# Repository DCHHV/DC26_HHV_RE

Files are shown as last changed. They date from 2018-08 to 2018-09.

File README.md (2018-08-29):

# DC26 HHV RE Challenge
DEF CON 26 Hardware Hacking Village Reverse Engineering Challenge

## Overview

This year's board features two challenge. The first part requires entering in the correct passcode using the four onboard buttons (labeled A, B, C, and D). Once the correct passcode has been entered, the middle, green LED will come on and the flag will be printed out via the serial interface. The second part of the challenge requires understanding how the second IC (the first being the ATtiny microcontroller) is used and manipulating that. The bottom, green LED will come on once that part is solved.

There are multiple ways to solve these challenges, and they are meant to be fun. If you're having trouble, or if you find a bug, reach out to [mediumrehr](https://www.twitter.com/mediumrehr)

Good luck!

## Instuctions

### Assembly
If your challenge isn't assembled, please see the hardware section for details on assembly. Most parts are explanitory as to where they go. For the surface mount parts, the 3-pack of resistors are for the LEDs, the 2-pack of resistors is for the RX line (only one of the resistors are necessary), and the single capacitor is used to reduce noise on the VCC input.

### Programming
There are two methods of loading the firmware onto the challenge board. Both require the same steps to start.

1. Connect the test points on the bottom of the challenge board to an arduino and add a capacitor between reset and GND on the Arduino UNO.

```
GND --> GND
SCK --> pin 13
MISO -> pin 12
MOSI -> pin 11
CS ---> pin 10
VCC --> 5V
```
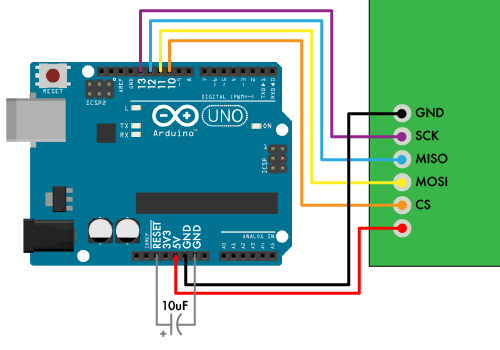
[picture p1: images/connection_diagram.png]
Connection diagram from programming


Note 1: If using an Uno (or another arduino board with 5V IO pins), make sure VCC is connected to 5V when programming. If IO pins are 3.3V, connect VCC to 3.3V when programming.

2. Bridge the two pads to the bottom right of the buttons.

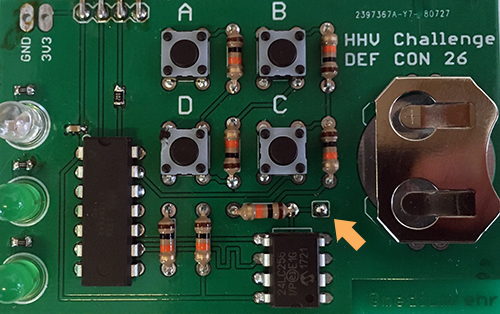
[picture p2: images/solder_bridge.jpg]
Programming solder bridge


3. Install the [Arduino IDE](https://www.arduino.cc/en/Main/Software "Arduino IDE Download").

4. Configure the Arduino as an ISP and add support to the Arduino IDE for the Attiny84 by [following this guide](http://highlowtech.org/?p=1695 "Guide for adding ATtiny84 support in Arduino IDE").

Now, here's where things split. You can either use the Arduino IDE to compile and upload the firmware onto the board, or you can use avrdude to program the already compiled code onto the board. The former requires installing a couple Arduino IDE libraries.

**Using the Arduino IDE**

1. Install the [TinyWireM](https://github.com/adafruit/TinyWireM) library by cloning/downloading and unzipping the project into `Arduino/libraries`, likely in your Documents folder.

2. Connect the Arduino to the computer and under the `Tools` menu, set `Board` to `ATtiny24/44/84`, `Processor` to `ATtiny84`, `Clock` to `Internal 1 MHz`, `Port` should be whatever port the Arduino UNO is plugged into, and `Programmer` to `Arduino as ISP`.

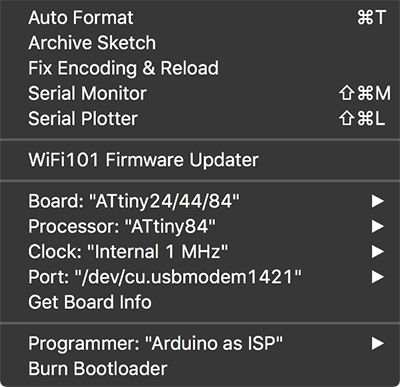
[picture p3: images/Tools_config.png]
Arduino Tools configuration


3. Burn the bootloader (and set the clock speed) by going back to `Tools` and clicking `Burn Bootloader`

4. Once the bootloader is burned onto the Attiny84, open `DC26_HHV_RE_setup.ino` and click the right-pointing arrow in the top left corner to upload the sketch. This will configure the challenges board before loading the challenge. The red LED should come on once this step is finished (if the LED hasn't come on after a couple seconds, it's likely something went wrong).

5. Open and upload `DC26_HHV_RE_obfuscated.ino` (DC26_HHV_RE.ino does the same thing, it's just easier to read and might give away some of the fun of the game if you read the wrong line or two) to finish loading the challenge.

Ensure that the red LED appears briefly upon pressing one of the buttons. If it does, you're good to go! Disconnect the programming wires and Arduino power before putting a battery into the battery holder.

6. Remove the solder bridge on the two pads to the bottom right of the buttons.

**Using avrdude**

avrdude has the benefit of allowing you to flash the hex file, and therefor not needing to install another library, or possibly spoil the surprises of the challenge.

1. Make sure you you know the location of avrdude and its config file, your programmer id, and the path to the mounted usb device. The config file will come after `-C`, the programmer id after `-c`, and the programmer mount location after `-P`.

In Mac OS, the avrdude will likely be under `/Applications/Arduino.app/Contents/Java/hardware/tools/avr/bin/avrdude` and its config will likely be under `/Applications/Arduino.app/Contents/Java/hardware/tools/avr/etc/avrdude.conf`. If you're using Windows, avrdude will likely be under `C:\Program Files (x86)\Arduino\hardware\tools\avr\bin\avrdude` and its config will likely be under `C:\Program Files (x86)\Arduino\hardware\tools\avr\etc\avrdude.conf`.

If you're using an Arduino as ISP, the programmer id is likely `stk500v1`, if you're using a bus pirate, the id is likely `buspirate`. For more examples of programmer ids, see [Ladyada's Avrdude Tutorial](http://www.ladyada.net/learn/avr/avrdude.html).

To find the programmer's port, follow [this guide](https://www.mathworks.com/help/supportpkg/arduinoio/ug/find-arduino-port-on-windows-mac-and-linux.html), or something similar.

2. Burn the bootloader. This script will setup the attiny84 bootloader and configure it to use the 1MHz internal clock:
```
/path/to/avrdude -C /path/to/avrdude.conf -v -p attiny84 -c stk500v1 -P /path/to/usbport -b 19200 -e -U efuse:w:0xff:m -U hfuse:w:0xdf:m -U lfuse:w:0x62:m
```

3. Load and run the setup sketch:
```
/path/to/avrdude -C /path/to/avrdude.conf -v -V -p attiny84 -c stk500v1 -P /path/to/usbport -b 19200 -U flash:w:/path/to/DC26_HHV_RE_setup.1MHz.hex:i
```

This will configure the challenges board before loading the challenge. The red LED should come on once this step is finished (if the LED hasn't come on after a couple seconds, it's likely something went wrong).

4. Load and run the challenge sketch:
```
/path/to/avrdude -C /path/to/avrdude.conf -v -V -p attiny84 -c stk500v1 -P /path/to/usbport -b 19200 -U flash:w:/path/to/DC26_HHV_RE.1MHz.hex:i
```

Ensure that the red LED appears briefly upon pressing one of the buttons. If it does, you're good to go! Disconnect the programming wires and Arduino power before putting a battery into the battery holder.

6. Remove the solder bridge on the two pads to the bottom right of the buttons.

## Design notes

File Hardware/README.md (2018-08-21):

# DC26 HHV RE Challenge
DEF CON 26 Hardware Hacking Village Reverse Engineering Challenge

## Assembly

The schematic, layout, and BOM are all included in this folder. Before assembling, make sure you have correct parts, and the correct amount of each.

```
SMD parts:
3 75 Ohm 0603 resistors
1* 1k Ohm 0805 resistor
1 0.1uF 0603 capacitor

TH parts:
1 ATtiny84 IC
1 24LC256 IC
4 Tactile switches 6mm
7 10k Ohm resistors
2 Green LEDs 5mm
1 Red LED 5mm
1 CR2032 battery holder
1 CR2032 battery

Not included, but likely necessary:
a handful of male headers
a serial reader
some connection wire

* if you received parts at DEF CON, you likely received this as a pack of 2, but you'll only need one
```

Below is what the assembled challenge board should look like:

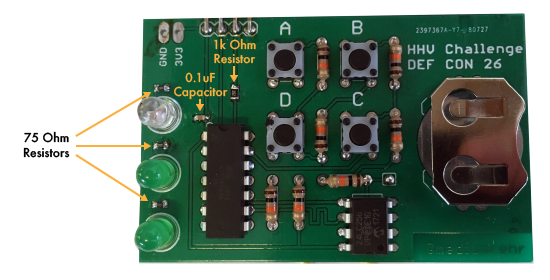
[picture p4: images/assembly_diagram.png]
Assembly diagram


Most of the through hole components can only go once place. The ATtiny and 24LC256 are directional, so make sure they oriented correctly (notches should line up with silkscreened indicators). The LEDs should be in the order of red (or clear), green, green from the top down. Surface mount componets are noted in the image above. The three 75 Ohm resistors should be placed directly above each LED, capacitor should be placed to the top left of the ATtiny84, and the 1k Ohm resistor should be placed on the RX serial line (above the ATtiny84).

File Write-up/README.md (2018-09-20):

## Write up

#### Pre challenge

Before starting the challenges, it's important to identify the 4-pin header at the top left of the board. This is the UART interface that is used to transmit the flags once they are unlocked. It also plays a role in solving part 1.

#### Part 1: Cracking the Passcode
There are a few ways to approach this problem. The intended way of solving the challeng is to perform a [side-channel attack](https://en.wikipedia.org/wiki/Side-channel_attack), but it is also possible to brute-force the passcode (there wasn't anything preventing this) since there are only 65536 possible combinations.

Using a logic analyzer and calculating the time delay between when a button is reported via UART and when the LED illuminates as feedback from a press, it's possible to deduce whether or not a passcode entry was correct (as long as the prior entries were correct). The image below shows three button presses; the first is correct and there is a 20ms delay between the UART (channel 2 in the image) report and the LED flashing (channel 3 in the image). The second button press is incorrect, resulting in a much shorter delay between report and flash. The third press will result in a short delay regardless or correctness since the system is designed to ignore following inputs once an incorrect passcode button press is entered.

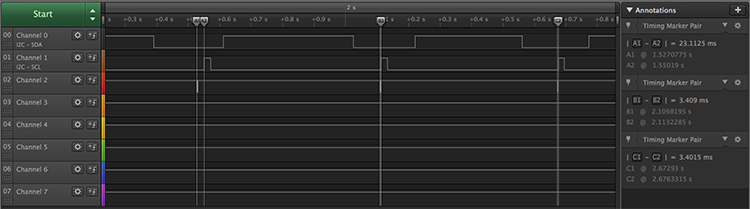
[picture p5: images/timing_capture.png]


The correct passcode is 14431212, and once it is entered, the middle LED will turn on and the flag "h3y_wh4ts_t3h_p4ssw0rd?" will be transmitted via the UART interface.

#### Part 2: Memory Manipulation

The second challenge utilizes the [24LC256 EEPROM](https://www.digikey.com/product-detail/en/microchip-technology/24LC256-I-P/24LC256-I-P-ND/273431). The microcontoller checks a specific address of the EEPROM on start-up, and if that address is set to a specific value, it will pass the challenge 2 check, turn on the bottom green LED, and output the flag via UART. There are two ways to start this challenge, either sniff the i2c lines running to the EEPROM to notice that the attiny is checking address 0x5A for a value on startup, or skip that step and dump the EEPROM. Dumping the EEPROM and entering the values into a hex to ascii converter will reveal the string "set address 0x5A to 0x26" starting at address 0x3.

There are two ways to go from here, you can either rewrite the EEPROM so that address 0x5A is set to 0x26, or you can disconnect the i2c lines from the EEPROM and create a device that spoofs the EEPROM interaction. The former route requires bridging the jumper (to the bottom right of the passcode buttons), disconnecting the write protect pin of the EEPROM. It's pulled high by default, but bridging that jumper pulls the pin low, disabling write protection and allowing the EEPROM to be changed.

Disconnecting the i2c lines from the EEPROM and connecting them to a new device that spoofs the interaction is also a way to pass this challenge. Using a microcontroller, you can set it up as an i2c slave that listens for requests on address 0x5A. Once an address comes through, respond with the value 0x26. Once the check is passed, the flag "0h_1_r3m3mb3r_n0w!" will be transmitted via the UART interface.

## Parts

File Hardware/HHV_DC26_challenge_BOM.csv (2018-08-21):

DC26 HHV RE Challenge BOM
Part | Value | Device | Package | Description | MF | MPN | Digikey PN | Digikey link
BT1 |  | Batter Holder |  | RETAINER BATT CR2025/2032 PC PIN | Linx Technologies Inc | BAT-HLD-001-THM | BAT-HLD-001-THM-ND | https://www.digikey.com/product-detail/en/linx-technologies-inc/BAT-HLD-001-THM/BAT-HLD-001-THM-ND/3044009
C1 | 0.1uF | Capacitor | 603 | CAP CER 0.1UF 25V X5R 0603 | Samsung Electro-Mechanics | CL10A104KA8NNNC | 1276-1857-1-ND | https://www.digikey.com/product-detail/en/samsung-electro-mechanics/CL10A104KA8NNNC/1276-1857-1-ND/3889943
D1 | Green | LED5MM | LED_5MM | LED GREEN DIFFUSED 5MM ROUND T/H | Marktech Optoelectronics | MT2118-G-A | 1125-1184-ND | https://www.digikey.com/product-detail/en/marktech-optoelectronics/MT2118-G-A/1125-1184-ND/4214619
D2 | Green | LED5MM | LED_5MM | LED GREEN DIFFUSED 5MM ROUND T/H
D3 | Red | LED5MM | LED_5MM | LED RED CLEAR 5MM ROUND T/H | Cree Inc. | C503B-RAN-CZ0C0AA2 | C503B-RAN-CZ0C0AA2CT-ND | https://www.digikey.com/product-detail/en/cree-inc/C503B-RAN-CZ0C0AA2/C503B-RAN-CZ0C0AA2CT-ND/6561767
IC1 |  | 24LC256P | DIL8 | IC EEPROM 256K I2C 400KHZ 8DIP | Microchip Technologies | 24LC256-I/P | 24LC256-I/P-ND | https://www.digikey.com/product-detail/en/microchip-technology/24LC256-I-P/24LC256-I-P-ND/273431
R1 | 75 | Resistor | 805 | RES SMD 75 OHM 5% 1/10W 0603 | Vishay Dale | CRCW060375R0JNEA | 541-75GCT-ND | https://www.digikey.com/product-detail/en/vishay-dale/CRCW060375R0JNEA/541-75GCT-ND/1179342
R2 | 75 | Resistor | 805 | RES SMD 75 OHM 5% 1/10W 0603
R3 | 75 | Resistor | 805 | RES SMD 75 OHM 5% 1/10W 0603
R10 | 1k | Resistor | 805 | RES SMD 1K OHM 5% 1/8W 0805 | Vishay Dale | CRCW08051K00JNEAC | 541-4162-1-ND | https://www.digikey.com/product-detail/en/vishay-dale/CRCW08051K00JNEAC/541-4162-1-ND/7928845
R6 | 10K | Resistor | AXIAL-0.3 | RES 10K OHM 1/4W 5% AXIAL | Stackpole Electronics Inc. | CF14JT10K0 | CF14JT10K0CT-ND | https://www.digikey.com/product-detail/en/stackpole-electronics-inc/CF14JT10K0/CF14JT10K0CT-ND/1830374
R7 | 10K | Resistor | AXIAL-0.3 | RES 10K OHM 1/4W 5% AXIAL
R8 | 10K | Resistor | AXIAL-0.3 | RES 10K OHM 1/4W 5% AXIAL
R9 | 10K | Resistor | AXIAL-0.3 | RES 10K OHM 1/4W 5% AXIAL
R11 | 10K | Resistor | AXIAL-0.3 | RES 10K OHM 1/4W 5% AXIAL
R12 | 10K | Resistor | AXIAL-0.3 | RES 10K OHM 1/4W 5% AXIAL
R13 | 10K | Resistor | AXIAL-0.3 | RES 10K OHM 1/4W 5% AXIAL
S1 |  | SPST Momentary Switch | TACTILE_SWITCH_PTH_6.0MM | SWITCH TACTILE SPST-NO 0.05A 12V | APEM Inc | MJTP1230 | 679-2428-ND | https://www.digikey.com/product-detail/en/apem-inc/MJTP1230/679-2428-ND/1798037
S2 |  | SPST Momentary Switch | TACTILE_SWITCH_PTH_6.0MM | SWITCH TACTILE SPST-NO 0.05A 12V
S3 |  | SPST Momentary Switch | TACTILE_SWITCH_PTH_6.0MM | SWITCH TACTILE SPST-NO 0.05A 12V
S4 |  | SPST Momentary Switch | TACTILE_SWITCH_PTH_6.0MM | SWITCH TACTILE SPST-NO 0.05A 12V
U$1 |  | ATTINY84-20PU | DIP14 | IC MCU 8BIT 8KB FLASH 14DIP | Microchip Technologies | ATTINY84A-PU | ATTINY84A-PU-ND | https://www.digikey.com/product-detail/en/microchip-technology/ATTINY84A-PU/ATTINY84A-PU-ND/2774082
Battery |  |  | Coin, 20mm | BATTERY LITHIUM 3V COIN 20MM | Panasonic - BSG | CR2032 | P189-ND | https://www.digikey.com/product-detail/en/panasonic-bsg/CR2032/P189-ND/31939

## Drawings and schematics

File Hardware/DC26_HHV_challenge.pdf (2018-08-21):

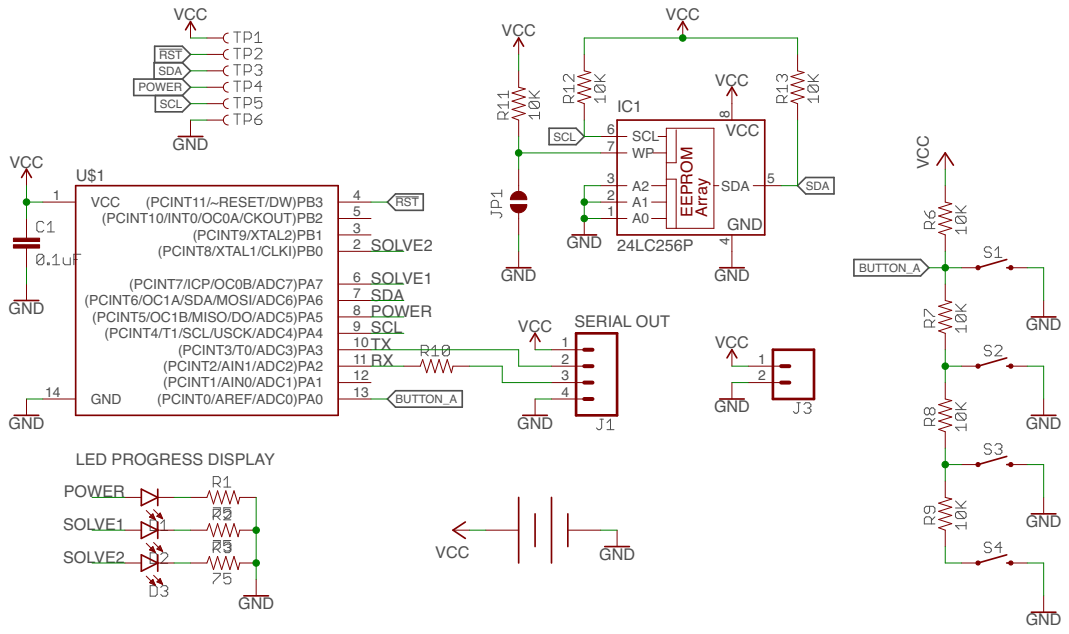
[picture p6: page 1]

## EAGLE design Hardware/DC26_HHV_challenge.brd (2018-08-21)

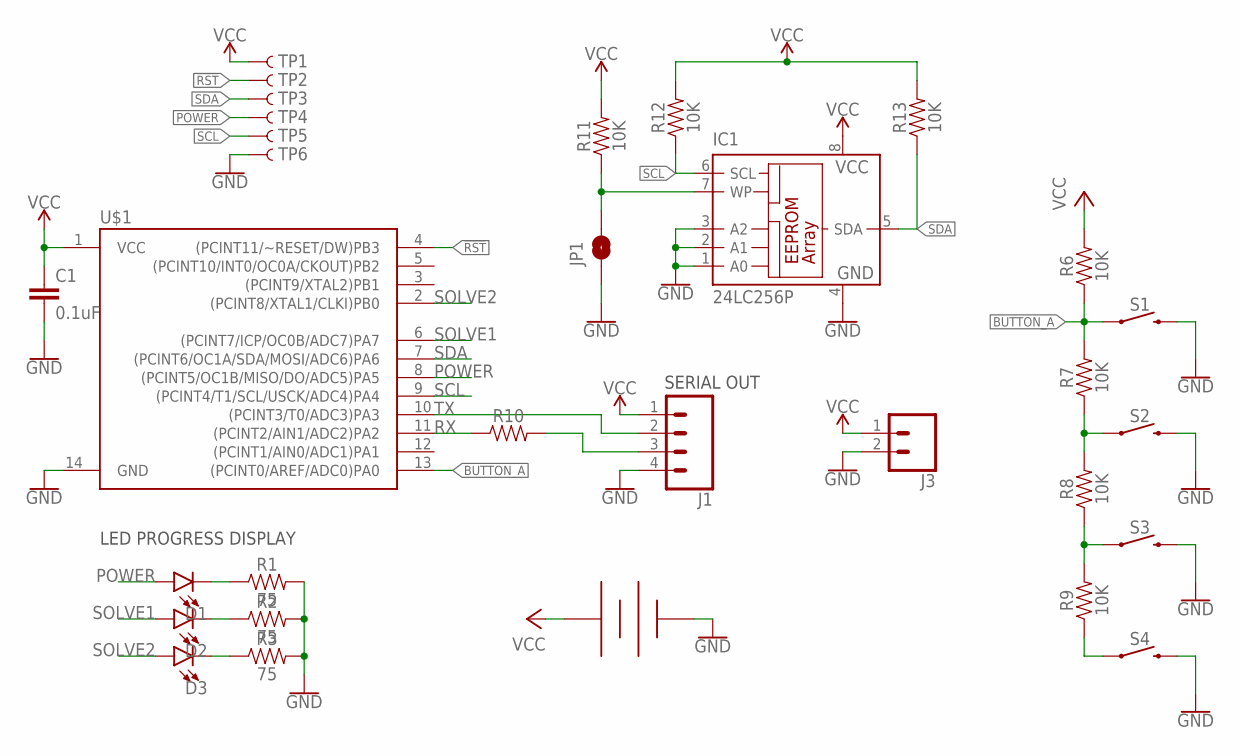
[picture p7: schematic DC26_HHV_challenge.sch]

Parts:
BT1: BAT-HLD-001-THM
C1: 0.1uF; 0603
D1, D2, D3: LED5MM; LED_5MM
IC1: 24LC256P; DIL8
J1: CONN_04LOCK; 1X04_LOCK
J3: CONN_02PTH3; 1X02_LONGPADS
JP1: JUMPER-SMT_2_NO_SILK; SMT-JUMPER_2_NO_SILK
R1, R2, R3: 75; 0805
R6, R7, R8, R9, R11, R12, R13: 10K; AXIAL-0.3
R10: 0805
S1, S2, S3, S4: MOMENTARY-SWITCH-SPST-PTH-6.0MM; TACTILE_SWITCH_PTH_6.0MM
TP1, TP2, TP3, TP4, TP5, TP6: TEST-POINT3X4; PAD.03X.04
U$1: ATTINY84ATTINY84-20PU; DIP14

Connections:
!RST: TP2.P$1, U$1.4 ((PCINT11/~RESET/DW)PB3)
BUTTON_A: R6.P$1 (1), R7.P$2 (2), S1.1, U$1.13 ((PCINT0/AREF/ADC0)PA0)
GND: BT1.- (VSS), C1.2, IC1.1 (A0), IC1.2 (A1), IC1.3 (A2), IC1.4 (GND), J1.4, J3.2, JP1.1, R1.2, R2.2, R3.2, S1.3 (2), S2.3 (2), S3.3 (2), S4.3 (2), TP6.P$1, U$1.14 (GND)
unnamed: R9.P$1 (1), S4.1
unnamed: R8.P$1 (1), R9.P$2 (2), S3.1
unnamed: R7.P$1 (1), R8.P$2 (2), S2.1
unnamed: D1.K (C), R1.1
unnamed: D2.K (C), R2.1
unnamed: D3.K (C), R3.1
unnamed: R10.1, U$1.11 ((PCINT2/AIN1/ADC2)PA2)
unnamed: IC1.7 (WP), JP1.2, R11.P$1 (1)
POWER: D1.A, TP4.P$1, U$1.8 ((PCINT5/OC1B/MISO/DO/ADC5)PA5)
RX: J1.3, R10.2
SCL: IC1.6 (SCL), R12.P$1 (1), TP5.P$1, U$1.9 ((PCINT4/T1/SCL/USCK/ADC4)PA4)
SDA: IC1.5 (SDA), R13.P$1 (1), TP3.P$1, U$1.7 ((PCINT6/OC1A/SDA/MOSI/ADC6)PA6)
SOLVE1: D2.A, U$1.6 ((PCINT7/ICP/OC0B/ADC7)PA7)
SOLVE2: D3.A, U$1.2 ((PCINT8/XTAL1/CLKI)PB0)
TX: J1.2, U$1.10 ((PCINT3/T0/ADC3)PA3)
VCC: BT1.+@0 (VCC), BT1.+@1 (VCC), BT1.+@2 (VCC), BT1.+@3 (VCC), C1.1, IC1.8 (VCC), J1.1, J3.1, R6.P$2 (2), R11.P$2 (2), R12.P$2 (2), R13.P$2 (2), TP1.P$1, U$1.1 (VCC)

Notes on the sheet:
SERIAL OUT
LED PROGRESS DISPLAY

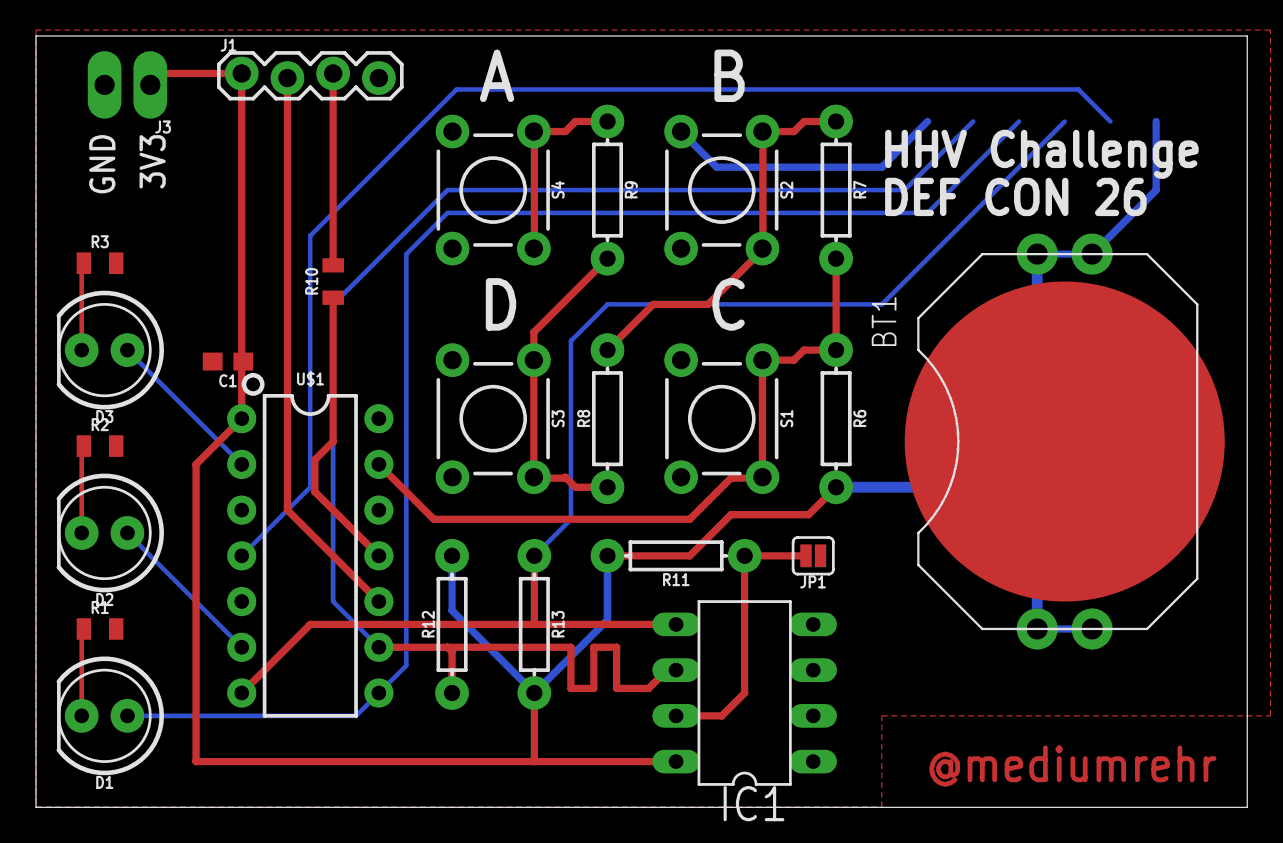
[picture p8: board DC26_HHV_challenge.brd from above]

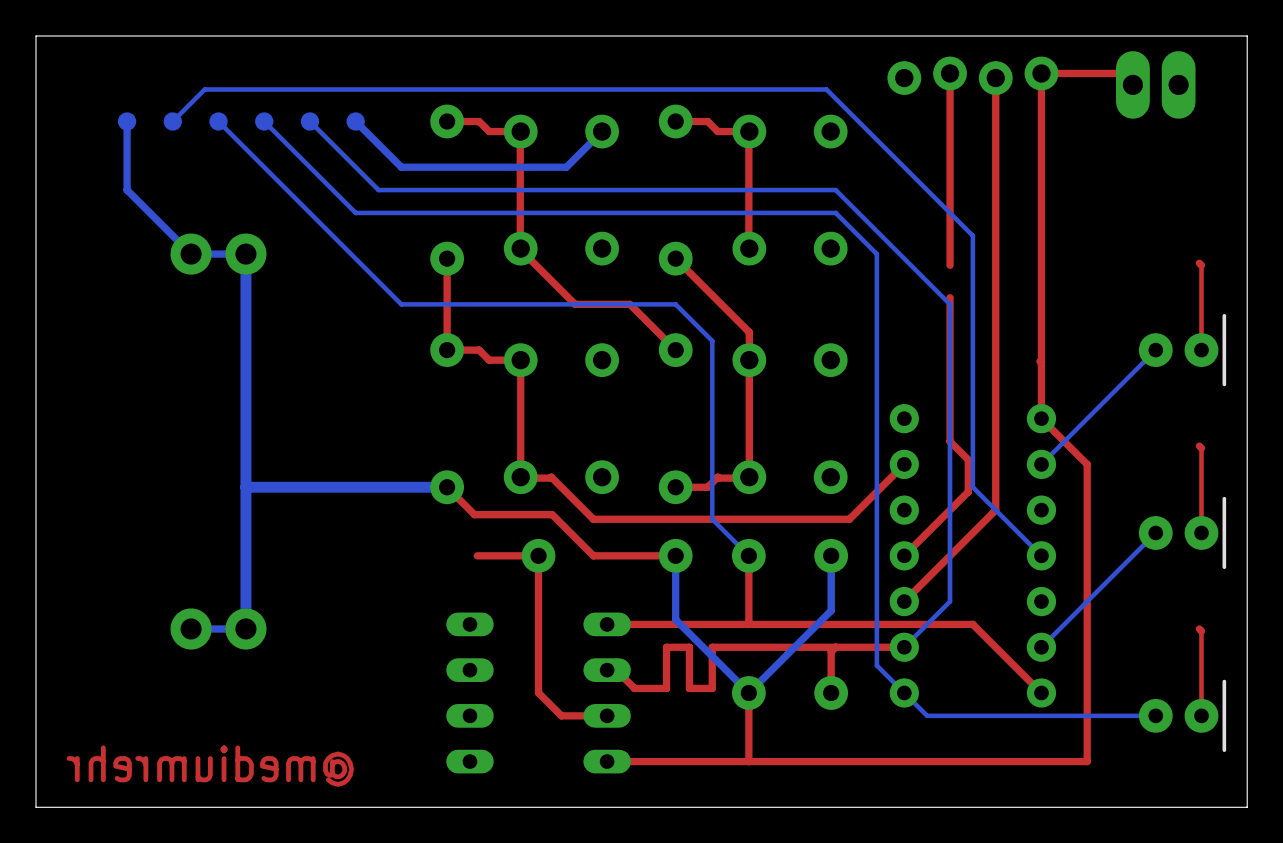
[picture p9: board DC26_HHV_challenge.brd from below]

Board: 2 copper layers, 67.3 x 42.9 mm, 31 parts (6 on the bottom side), 19 nets.

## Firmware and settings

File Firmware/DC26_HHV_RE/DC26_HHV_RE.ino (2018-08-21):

#include <SoftwareSerial.h>
#include <TinyWireM.h>

#define RX  2
#define TX  3
SoftwareSerial Serial(RX, TX);

#define PASSLENGTH  8 // length of passcode

#define EEPROM_ADDR 0x50 // 7 bit I2C address for EEPROM

bool keyPressed = false;            // debouncing 
uint16_t lastKeyState = 1023;       // the previous reading from the input pin
uint8_t keysEntered = 0;            // keep track on passcode keys entered
uint8_t userPass[PASSLENGTH] = {0}; // passcode entered by user
bool wrongPass = false;             // flag
uint8_t password[PASSLENGTH] = {1, 4, 4, 3, 1, 2, 1, 2}; // the correct passcode

void setup() {
  // put your setup code here, to run once:
  Serial.begin(9600); // initialize serial
  TinyWireM.begin();  // initialize I2C
  delay(100);
  Serial.println("welcome to the DC 26 HHV Challenge!");

  // set IO directions
  pinMode(0, INPUT);
  pinMode(5, OUTPUT);
  pinMode(7, OUTPUT);
  pinMode(10, OUTPUT);

  // set IO initial states
  digitalWrite(5, LOW);
  digitalWrite(7, LOW);
  digitalWrite(10, LOW);

  // check if eeprom corrected
  if (checkEEPROM()) {
    digitalWrite(5, HIGH);
    Serial.println("Challenge 2: complete");
    Serial.println("flag: 0h_1_r3m3mb3r_n0w!");
  }

  // prompt for challenge 1
  Serial.println("Challenge 1:");
  Serial.println("Enter the correct passcode");
}

void loop() {
  // put your main code here, to run repeatedly:
  // watch for button input (aka A0 != 1023)
  uint16_t key = analogRead(0);
  
  if (key < 1000) {
    // poor man's debounce
    lastKeyState = key;
    delay(50);
    if ((key == lastKeyState) & (!keyPressed)) {
      // new button pressed
      keyPressed = true;
      uint8_t value = 0;
      if ((key > 740) & (key < 800)) {
        // A pressed; value should be ~769
        value = 1;
        Serial.println("A");
      } else if ((key > 480) & (key < 550)) {
        // B pressed; value should be ~512
        value = 2;
        Serial.println("B");
      } else if ((key >= 0) & (key < 50)) {
        // C pressed; value should be ~0
        value = 3;
        Serial.println("C");
      } else if ((key > 650) & (key < 730)) {
        // D pressed; value should be ~684
        value = 4;
        Serial.println("D");
      }

      // store and check passcode
      userPass[keysEntered] = value;
      checkPassword(value, keysEntered);
      keysEntered++;

      // reset once more than PASSLENGTH keys entered
      if (keysEntered >= PASSLENGTH) {
        keysEntered = 0;
        wrongPass = false;
        for (int i=0; i < 4; i++) {
          userPass[i] = 0;
        }
      }
    }
  } else {
    // key released
    keyPressed = false;
  }
  delay(100);
}

// checks latest key entered
void checkPassword(uint8_t key, uint8_t count) {
  if (!wrongPass) {
    // everything has been correct so far
    if (key == password[count]) {
      // small delay to make it a little easier to pick
      // up on correct vs incorrect key presses
      delay(20);
    } else {
      wrongPass = true;
    }
  }

  // LED feedback to show button was pressed
  digitalWrite(10, HIGH);
  delay(20);
  digitalWrite(10, LOW);

  if (count >= (PASSLENGTH - 1)) {
    // all keys entered, check if passcode is still correct
    if (wrongPass) {
      digitalWrite(10, HIGH);
      delay(1000);
      digitalWrite(10, LOW);
    } else {
      // winner winner!
      digitalWrite(7, HIGH);
      Serial.println("Challenge 1: complete");
      Serial.println("flag: h3y_wh4ts_t3h_p4ssw0rd?");
    }
  }
}

byte readEEPROM(int deviceaddress, unsigned int eeaddress ) 
{
  byte rdata = 0xFF;
 
  TinyWireM.beginTransmission(deviceaddress);
  TinyWireM.send((int)(eeaddress >> 8));   // MSB
  TinyWireM.send((int)(eeaddress & 0xFF)); // LSB
  TinyWireM.endTransmission();
 
  TinyWireM.requestFrom(deviceaddress,1);
 
  if (TinyWireM.available()) rdata = TinyWireM.receive();
 
  return rdata;
}

// read a specific eeprom address and check if it was
// changed to the correct value
uint8_t checkEEPROM() {
  byte readData = readEEPROM(EEPROM_ADDR, 0x5A);

  if (readData == 0x23) {
    return 1;
  }
  
  return 0;
}

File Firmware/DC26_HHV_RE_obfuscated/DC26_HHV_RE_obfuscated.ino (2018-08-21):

/*
 * DEF CON 26 HHV Challenge
 *   Challenge sketch
 *   @mediumrehr
 *   Aug 2018
 * 
 * Make sure to load the Setup sketch first!
 * 
 * When programming this sketch onto the challenge board,
 * make sure the bootloader clock speed is the same as the
 * clock speed set for uploading this sketch!
 */
 
 #include "obfuscator.h"
void setup(){s();Spl(s0);pm(0,0);pm(5,1);pm(7,1);pm(10,1);dw(5,0);dw(7,0);dw(10,0);if(cE()){dw(5,1);Spl(s1);Spl(s2);}Spl(s3);Spl(s4);}
void loop(){uint16_t key=ar(0);
  if(key<900){lks=key;d(50);
    if((key==lks)&(!kp)){
      kp=1;uint8_t value=0;
      if((key>740)&(key<800)){value=1;Spl((char)0x41);}
      else if((key>480)&(key<550)){value=2;Spl((char)0x42);}
      else if((key>=0)&(key<50)){value=3;Spl((char)0x43);}
      else if((key>650)&(key<730)){value=4;Spl((char)0x44);}
      up[ke]=value;cP(value,ke);ke++;
      if(ke>=8){ke=0;wp=0;for(i=0;i<4;i++){up[i]=0;}}
    }}else{kp=0;}
  d(100);}
void cP(uint8_t key, uint8_t count){
  if(!wp){if(key==pw[count]){d(20);}else{wp=1;}}
  dw(10,1);d(20);dw(10,0);
  if(count>=(8-1)){
    if(wp){dw(10,1);Spl(s7);d(1000);dw(10,0);}
    else{dw(7,1);Spl(s5);Spl(s6);}}}

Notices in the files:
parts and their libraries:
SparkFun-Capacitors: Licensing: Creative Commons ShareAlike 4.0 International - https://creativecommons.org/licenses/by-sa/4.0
